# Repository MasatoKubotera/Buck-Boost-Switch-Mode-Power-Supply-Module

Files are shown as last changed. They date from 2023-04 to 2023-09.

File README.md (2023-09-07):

<html lang="en">

<head>
	<meta charset="uft-8">
	<meta name="author" content="Masato Kubotera">
    <meta name="description" content="">
</head>

<body>
    <p><strong>This product is currently under development!</strong></p>
	<h1>Buck-Boost Switch Mode Power Supply Module</h1>
        <p>
            <table>
                <tr>
                    <th>Top Surface of PCB</th>
                    <th>Bottom Surface of PCB</th>
                    <th>Assembled Electronic Components</th>
                </tr>
                <tr>
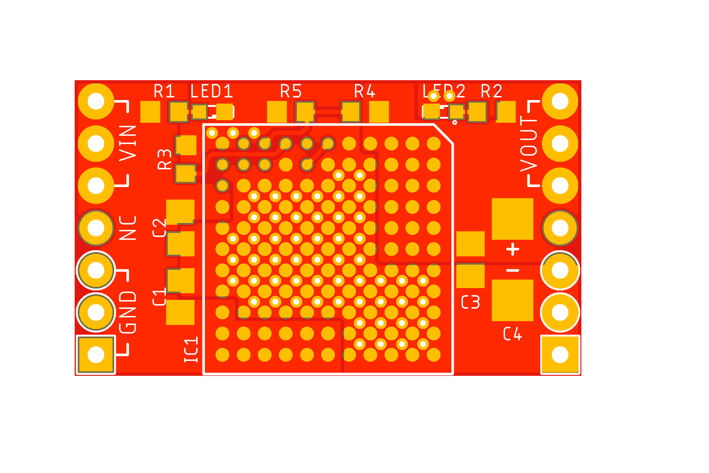
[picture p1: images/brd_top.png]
                    <td></td>
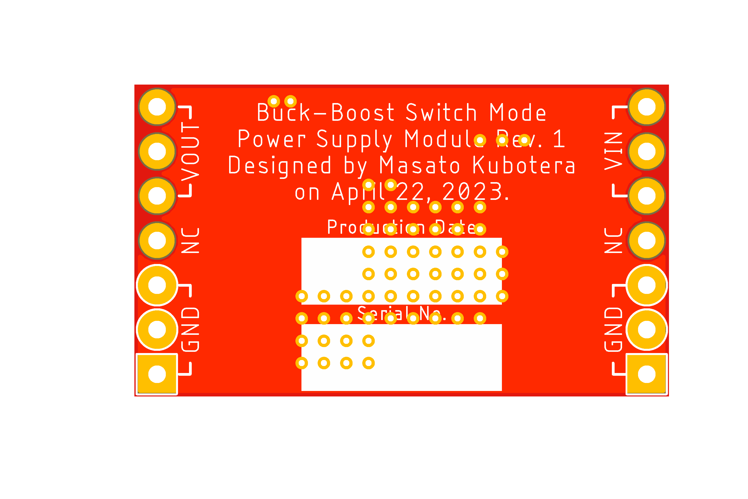
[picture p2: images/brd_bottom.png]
                    <td></td>
                    <td></td>
                </tr>
            </table>
        </p>
	<h2>Features Rev. 1</h2>
        <p>
            This product is a buck-boost switch mode power supply module using Analog Devices <a href="https://www.analog.com/en/products/ltm8055.html">LTM8055</a>. Supports the wide voltage input range of 5V to 36V. The output current and switching frequency are determined by the resistor value to be mounted.<br>
            This product was designed with a recommended 12V/6A output and a switching frequency of 600kHz. However, it was later changed to 18V/5A output and 800kHz switching frequency to suit SUSTAINA-OP<sup>TM</sup> applications.
        </p>
    <h3>PCB</h3>
        <p>
            <ul>
                <li>12" x 7" (30.48 mm x 17.78 mm) PCB layout</li>
                <li>1" (2.54mm) pitch through-holes for pin headers
                    <ul>
                        <li>1 x 7 pin headers - 1
                            <ul>
                                <li><strong>3x VIN</strong>: Power In (5V to 36V)</li>
                                <li><strong>1x NC</strong>: Non Connection</li>
                                <li><strong>3x GND</strong>: Common Ground</li>
                            </ul>
                        </li>
                        <li>1 x 7 pin headers - 2
                            <ul>
                                <li><strong>3x VOUT</strong>: Power Out (Regulated 18V)</li>
                                <li><strong>1x NC</strong> Non Connection</li>
                                <li><strong>3x GND</strong>: Common Ground</li>
                            </ul>
                        </li> 
                    </ul>
                </li>
            </ul>
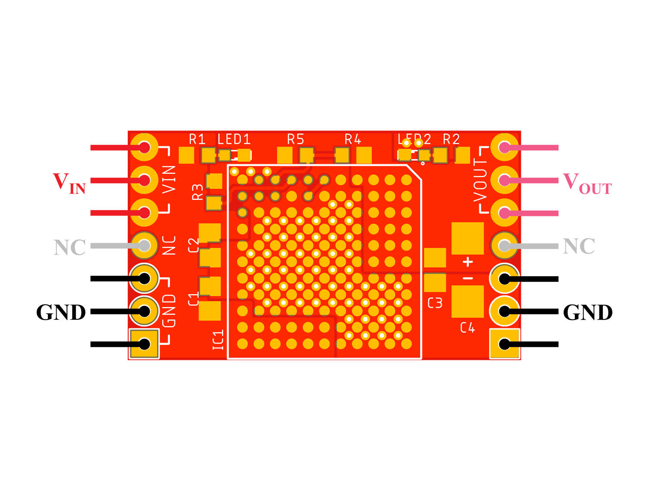
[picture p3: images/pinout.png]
            
        </p>
    <h3><a href="https://www.analog.com/en/products/ltm8055.html">LTM8055</a></h3>
        <p>
            <ul>
                <li>Complete Buck-Boost Switch Mode Power Supply</li>
                <li>VOUT Equal, Greater, Less Than VIN</li>
                <li>Wide Input Voltage Range: 5V to 36V</li>
                <li>12V/3A Output from 6VIN</li>
                <li>12V/6A Output from 12VIN</li>
                <li>12V/8.5A Output from 24VIN</li>
                <li>Up to 97.5% Efficient</li>
                <li>Adjustable Input and Output Average Current Limits</li>
            </ul>
        <p>
	<h2>Development Environments</h2>
    <p>
        This product is designed with the following software.
            <ul>
                <li><a href="https://www.autodesk.com/products/eagle/overview">Autodesk Eagle 9.6.2</a></li>
            </ul>
    </p>
    <h2>Repository Contents</h2>
        <p>
            <dl>
                <dt><a href="/images">\images</a></dt>
                <dd>PCB preview images and capture of design screen</dd>
                <dt><a href="/libraries">\libraries</a></dt>
                <dd>Libraries used in Autodesk Eagle design</dd>
                <dt><a href="/documents">\documents</a> </dt>
                <dd>Documentation for making and using this product</dd>
                <dt><a href="/pcb_order">\pcb_order</a> </dt>
                <dd>Gerber data and documentation for ordering PCB</dd>
                <dt><a href="/schematic.pdf">schematic.pdf</a></dt>
                <dd>Circuit diagram of this product</dd>
                <dt>*.brd</dt>
                <dd>Board wiring design file by Autodesk Eagle</dd>
                <dt>*.sch</dt>
                <dd>Circuit diagram design file by Autodesk Eagle</dd>
                <dt><a href="/.gitignore">.gitignore</a></dt>
                <dd>A file that tells Git not to track a particular file</dd>            <dt><a href="/LICENSE">LICENSE</a></dt>
                <dd>License to use this product</dd>
            </dl>
        </p>
    <h2>Documentation</h2>
        <p>
            The following documents are available for this product.
            <ul>
                <li><a href="/pcb_order/README.md">\pcb_order\README.md</a>: Information for ordering the PCB</li>
                <li><a href="/documents/BOM.md">\document\BOM.md</a>: List of electronic components assembled on the PCB</li>
            </ul>
        </p>
    <h3>Note</h3>
    <h4>Die due to temperature</h4>
        <p>
            The die temperature of the LTM8055/LTM8055-1 must be lower than the maximum rating of 125°C. Therefore, it is recommended that the following heat sinks be affixed to the LTM8055/LTM8055-1.<br>
            Details: <a href="https://www.analog.com/media/en/technical-documentation/data-sheets/LTM8055-8055-1.pdf#page=18">Analog Devices LTM8055/LTM8055-1 Data Sheet Page#18</a>
            <ul>
                <li><a href="https://amzn.asia/d/5Kmnowi">Awxlumv Aluminum Heatsink 14mm x 14mm x 6mm</a></li>
            </ul>
        </p>
    <h4>Output voltage and switching frequency</h4>
        <p>
            The output voltage of LTM8055/LTM8055-1 is determined by R4 and R5 on the board, and the switching frequency by R3. If the voltage is set other than the recommended configuration voltage, the voltage is determined by the following equation.<br>
            Output voltage [V] = 1.2 * (1 + R4 / R5)<br>
            Details: <a href="https://www.analog.com/media/en/technical-documentation/data-sheets/LTM8055-8055-1.pdf#page=10">Analog Devices LTM8055/LTM8055-1 Data Sheet Page#10</a>
        </p>
    <h2>References</h2>
        <p>
            This product was designed with reference to the following products.
            <ul>
                <li><a href="https://www.analog.com/jp/design-center/evaluation-hardware-and-software/evaluation-boards-kits/dc2017a.html">Analog Devices DC2017A: LTM8055 Demo Board</a></li>
            </ul>
        </p>
    <h2>Contact</h2>
        <p>
            If you have any questions, please contact the designer of this product, Masato Kubodera, by <a href="mailto:masato.kubotera@sustaina-op.com">e-mail</a>.<br>
            E-mail: <a href="mailto:masato.kubotera@sustaina-op.com">masato.kubotera@sustaina-op.com</a>
        </p>
    <h2>License Information</h2>
        <p>
            This product is open source. Please review the <a href="/LICENSE">LICENSE</a> for license information.<br>
            <br>
            This product by Masato Kubotera is licensed under a <a href="http://creativecommons.org/licenses/by-nc-sa/4.0/">Creative Commons Attribution-NonCommercial-ShareAlike 4.0 International License</a>.
        </p>
</body>
</html>

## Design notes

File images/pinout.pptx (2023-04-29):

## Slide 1

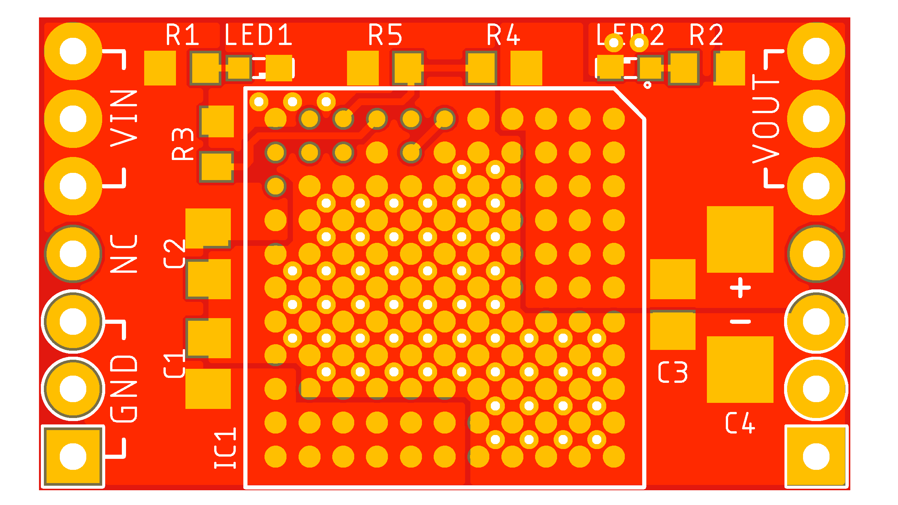
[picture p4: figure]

VOUT

NC

GND

VIN

NC

GND

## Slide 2

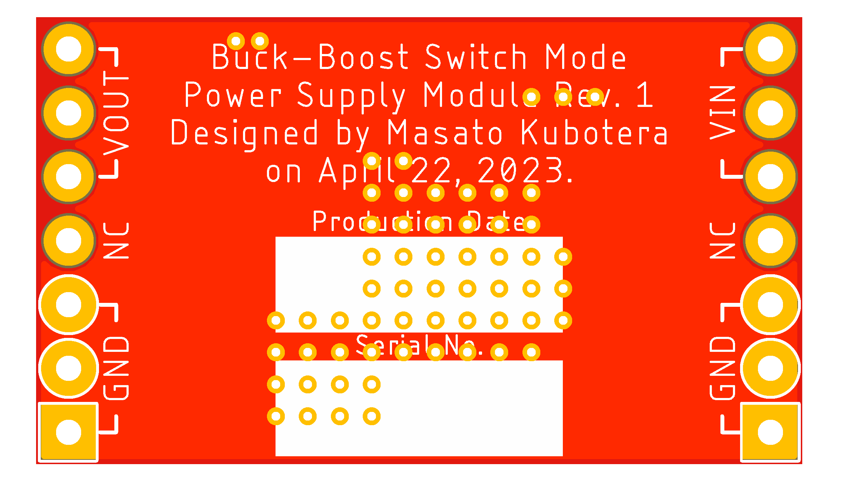
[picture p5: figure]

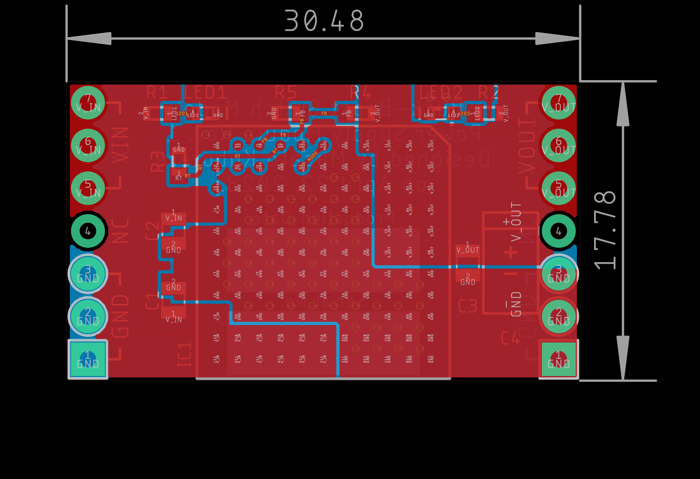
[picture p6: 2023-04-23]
images/brd.png

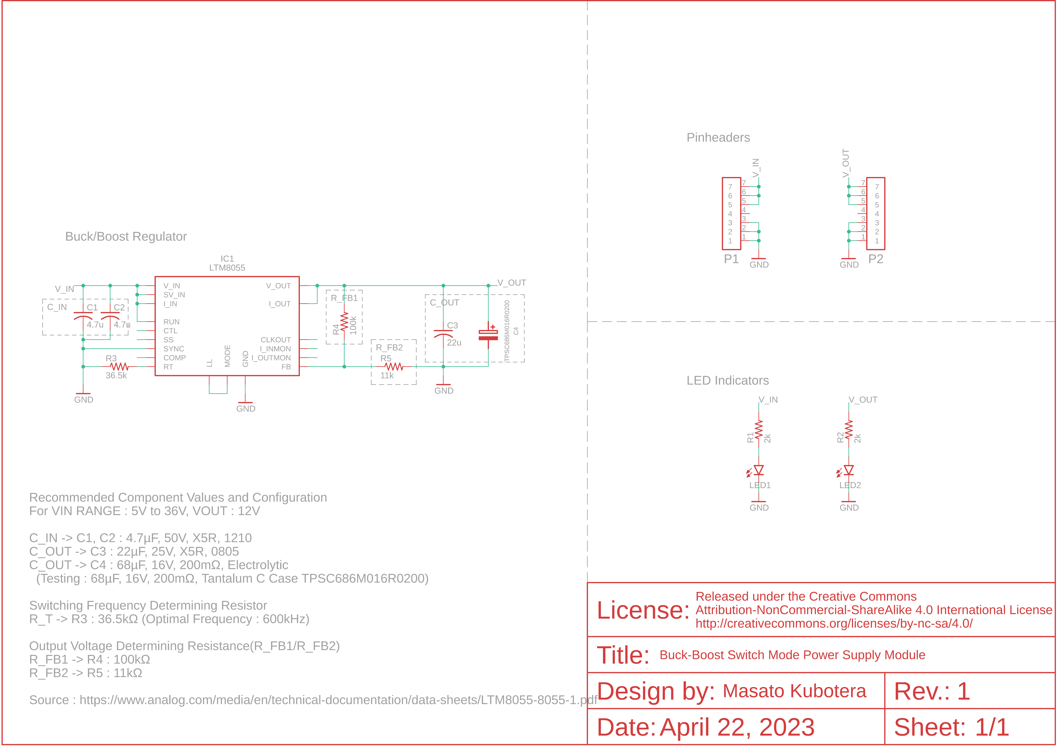
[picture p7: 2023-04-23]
images/sch.png

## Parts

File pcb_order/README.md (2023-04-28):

<html lang="en">

<head>
	<meta charset="uft-8">
	<meta name="author" content="Masato Kubotera">
    <meta name="description" content="">
</head>

<body>
	<h1>PCB Order</h1>
        <p>
            PCB ordering were outsourced to <a href="https://jlcpcb.com/">JLCPCB</a>.<br>
            The following files were used to generate files for PCB orders.
            <ul>
                <li>Eagle Design File:
                    <a href="https://github.com/JLCPCB/jlcpcb-eagle/blob/master/design%20rules/jlcpcb-2layers.dru">jlcpcb-2layers.dru</a>
                </li>
                <li>Eagle CAM File:
                    <a href="https://github.com/JLCPCB/jlcpcb-eagle/blob/master/cam/jlcpcb_2_layer_v9.cam">jlcpcb_2_layer_v9.cam</a>
                </li>
            </ul>
            These are distributed in <a href="https://github.com/JLCPCB/jlcpcb-eagle">github.com/JLCPCB/jlcpcb-eagle</a>.<br>
        </p>
    <h2>PCB Order Specifications</h2>
        <p>           
            <table>
                <tr>
                    <th>PCB Top Image</th>
                    <th>PCB Bottom Image</th>
                </tr>
                <tr>
                    <td></td>
                    <td></td>
                </tr>
            </table>
            The following files used to order the PCB and their specifications. 
            <ul>
                <li>Gerber data: <a href="Gerber_date.zip">Gerber_date.zip</a></li>
            </ul>
            <details close>
                <summary>Click for more specifications</summary>
                <ul>                
                    <li>Base Material: FR-4</li>
                    <li>Layers: 2</li>
                    <li>Dimension: 30.48mm* 17.78mm</li>
                    <li>Product Type: Industrial/Consumer electronics</li>
                    <li>Different Design: 1</li>
                    <li>Delivery Format: Single PCB</li>
                    <li>PCB Thickness: 1.6</li>
                    <li>Impedance Control: no</li>
                    <li>PCB Color: Red</li>
                    <li>Silkscreen: White</li>
                    <li>Surface Finish: HASL(with lead)</li>
                    <li>Outer Copper Weight: 1 oz</li>
                    <li>Via Covering: Tented</li>
                    <li>Board Outline Tolerance: ±0.2mm(Regular)</li>
                    <li>Confirm Production file: No</li>                
                    <li>Remove Order Number: Yes</li>
                    <li>Deburring/Edge rounding: No</li>
                    <li>Flying Probe Test: Fully Test</li>
                    <li>Gold Fingers: No</li>
                    <li>Castellated Holes: No</li>
                    <li>4-Wire Kelvin Test: No</li>
                    <li>Paper between PCBs: No</li>
                    <li>Appearance Quality: IPC Class 2 Standard</li>
                    <li>Silkscreen Technology: Ink-jet/Screen Printing</li>
                    <li>Package Box: With JLCPCB logo</li>
                </ul>
            </details>
        </p>
        <h2>SMT Stencil Order Specifications</h2>
        <p>           
            <details close>
                <summary>Click for more specifications</summary>
                <ul>                
                    <li>Framework: No</li>                
                    <li>Step Stencil: No</li>                
                    <li>Dimension: 380mm*280mm</li>                
                    <li>Stencil Side: Top</li>                
                    <li>Electropolishing: Sanding</li>                
                    <li>Fiducials: No Fiducial</li>                
                    <li>Confirm Production file:: No</li>
                </ul>
            </details>
        </p>
</body>
</html>

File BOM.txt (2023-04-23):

Qty Value            Device           Package          Parts      Description                
2                    LEDSML0603       SML0603          LED1, LED2 LED                        
1   100k             R-US_R0603       R0603            R4         RESISTOR, American symbol  
1   11k              R-US_R0603       R0603            R5         RESISTOR, American symbol  
1   22u              C-USC0805        C0805            C3         CAPACITOR, American symbol 
2   2k               R-US_R0603       R0603            R1, R2     RESISTOR, American symbol  
1   36.5k            R-US_R0603       R0603            R3         RESISTOR, American symbol  
2   4.7u             C-USC0805        C0805            C1, C2     CAPACITOR, American symbol 
1   LTM8055          LTM8055          LTM8055          IC1                                   
2   PINHEADER-7P     PINHEADER-7P     7P               P1, P2                                
1   TPSC686M016R0200 TPSC686M016R0200 TPSC686M016R0200 C4

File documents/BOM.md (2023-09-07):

<html lang="en">

<head>
	<meta charset="uft-8">
	<meta name="author" content="Masato Kubotera">
    <meta name="description" content="">
</head>

<body>
	<h1>BOM</h1>
        <p>
        The following electronic components are used for assembly on the PCB.
        <table>
                <tr>
                    <th>Top Designator</th>
                    <th>MFR.Part #</th>
                    <th>Distributor / Part #</th>
                    <th>Manufacturer</th>
                    <th>Part Detail</th>
                </tr>
                <tr>
                    <td>IC1</td>
                    <td>LTM8055IY#PBF</td>
                    <td><a href="https://www.mouser.jp/ProductDetail/584-LTM8055IY%23PBF">Mouser / 584-LTM8055IY#PBF</a></td>
                    <td><a href="https://www.analog.com/en/products/ltm8055.html">Analog Devices</a></td>
                    <td>Switching Voltage Regulator SMD Buck-Boost 36V 8.5A BGA-121</td>
                </tr>
                <tr>
                    <td>C1, C2</td>
                    <td>CL21A475KBQNNNE</td>
                    <td><a href="https://akizukidenshi.com/catalog/g/gP-07548/">Akizuki / P-07548</a></td>
                    <td><a href="https://product.samsungsem.com/mlcc/CL21A475KBQNNN.do">Samsung Electronics</a></td>
                    <td>Multilayer Ceramic Capacitor SMD 4.7uF 50V ±10% X5R 0805</td>
                </tr>
                <tr>
                    <td>C3</td>
                    <td>GRM21BR61E226ME44</td>
                    <td><a href="https://akizukidenshi.com/catalog/g/gP-08240/">Akizuki / P-08240</a></td>
                    <td><a href="https://www.murata.com/en-us/products/productdetail?partno=GRM21BR61E226ME44%23">Murata Electronics</a></td>
                    <td>Multilayer Ceramic Capacitor SMD 22uF 25V ±20% X5R 0805</td>
                </tr>
                <tr>
                    <td>C4</td>
                    <td>TPSC686M016R0200</td>
                    <td><a href="https://www.mouser.jp/ProductDetail/581-TPSC686M016R0200">Mouser / 581-TPSC686M016R0200</a></td>
                    <td><a href="https://www.kyocera-avx.com/products/tantalum/smd-tantalum-mno2/tps-series/">KYOCERA AVX</a></td>
                    <td>Tantalum Capacitor SMD 68uF 16V ±20% 2312</td>
                </tr>
                <tr>
                    <td>LED1, LED2</td>
                    <td>150060VS86000</td>
                    <td><a href="https://www.mouser.jp/ProductDetail/710-150060VS86000">Mouser / 710-150060VS86000</a></td>
                    <td><a href="https://www.we-online.com/components/products/datasheet/150060VS86000.pdf">Wurth Elektronik</a></td>
                    <td>Standard LED SMD 2V 20mA GREEN 573nm 0603</td>
                </tr>
                <tr>
                    <td>P1, P2</td>
                    <td>PH-1x40SG</td>
                    <td><a href="https://akizukidenshi.com/catalog/g/gC-00167/">Akizuki / C-00167</a></td>
                    <td><a href="">Useconn Electronics</a></td>
                    <td>Pin Header Straight 2.54mm Pitch 3A 20mΩ 500V</td>
                </tr>
                <tr>
                    <td>R1, R2</td>
                    <td>RC0603FR-102KL</td>
                    <td><a href="https://www.mouser.jp/ProductDetail/603-RC0603FR-102KL">Mouser / 603-RC0603FR-102KL</a></td>
                    <td>YAGEO</td>
                    <td>Thick Film Resistor SMD 2kΩ 1/10W ±1% 0603</td>
                </tr>
                <tr>
                    <td>R3</td>
                    <td>CPF0603B45K3E1</td>
                    <td><a href="https://jp.rs-online.com/web/p/surface-mount-resistors/1228879">RS Components /122-8879 </a></td>
                    <td>TE Connectivity</td>
                    <td>Thick Film Resistor SMD 45.3kΩ 0.063W ±0.1% 0603</td>
                </tr>
                <tr>
                    <td>R4</td>
                    <td>RC0603FR-07100KL</td>
                    <td><a href="https://www.mouser.jp/ProductDetail/603-RC0603FR-07100KL">Mouser / 603-RC0603FR-07100KL</a></td>
                    <td>YAGEO</td>
                    <td>Thick Film Resistor SMD 100kΩ 1/10W ±1% 0603</td>
                </tr>
                <tr>
                    <td>R5</td>
                    <td>ERA3APB6981V</td>
                    <td><a href="https://jp.rs-online.com/web/p/surface-mount-resistors/8409357">RS Components / 840-9357L</a></td>
                    <td>Panasonic</td>
                    <td>Thick Film Resistor SMD 6.98kΩ 1/10W ±0.1% 0603</td>
                </tr>
            </table>
            For a configuration with output voltage/current of 12V/6A, change to the following.
            <table>
                <tr>
                    <th>Top Designator</th>
                    <th>MFR.Part #</th>
                    <th>Distributor / Part #</th>
                    <th>Manufacturer</th>
                    <th>Part Detail</th>
                </tr>
                <tr>
                    <td>R3</td>
                    <td>RC0603FR-0736K5L</td>
                    <td><a href="https://www.mouser.jp/ProductDetail/603-RC0603FR-0736K5L">Mouser /603-RC0603FR-0736K5L </a></td>
                    <td>YAGEO</td>
                    <td>Thick Film Resistor SMD 36.5kΩ 1/10W ±1% 0603</td>
                </tr>
                <tr>
                    <td>R5</td>
                    <td>RC0603JR-0711KL</td>
                    <td><a href="https://www.mouser.jp/ProductDetail/603-RC0603JR-0711KL">Mouser / 603-RC0603JR-0711KL</a></td>
                    <td>YAGEO</td>
                    <td>Thick Film Resistor SMD 11kΩ 1/10W ±1% 0603</td>
                </tr>
            </table>
        </p>
</body>
</html>

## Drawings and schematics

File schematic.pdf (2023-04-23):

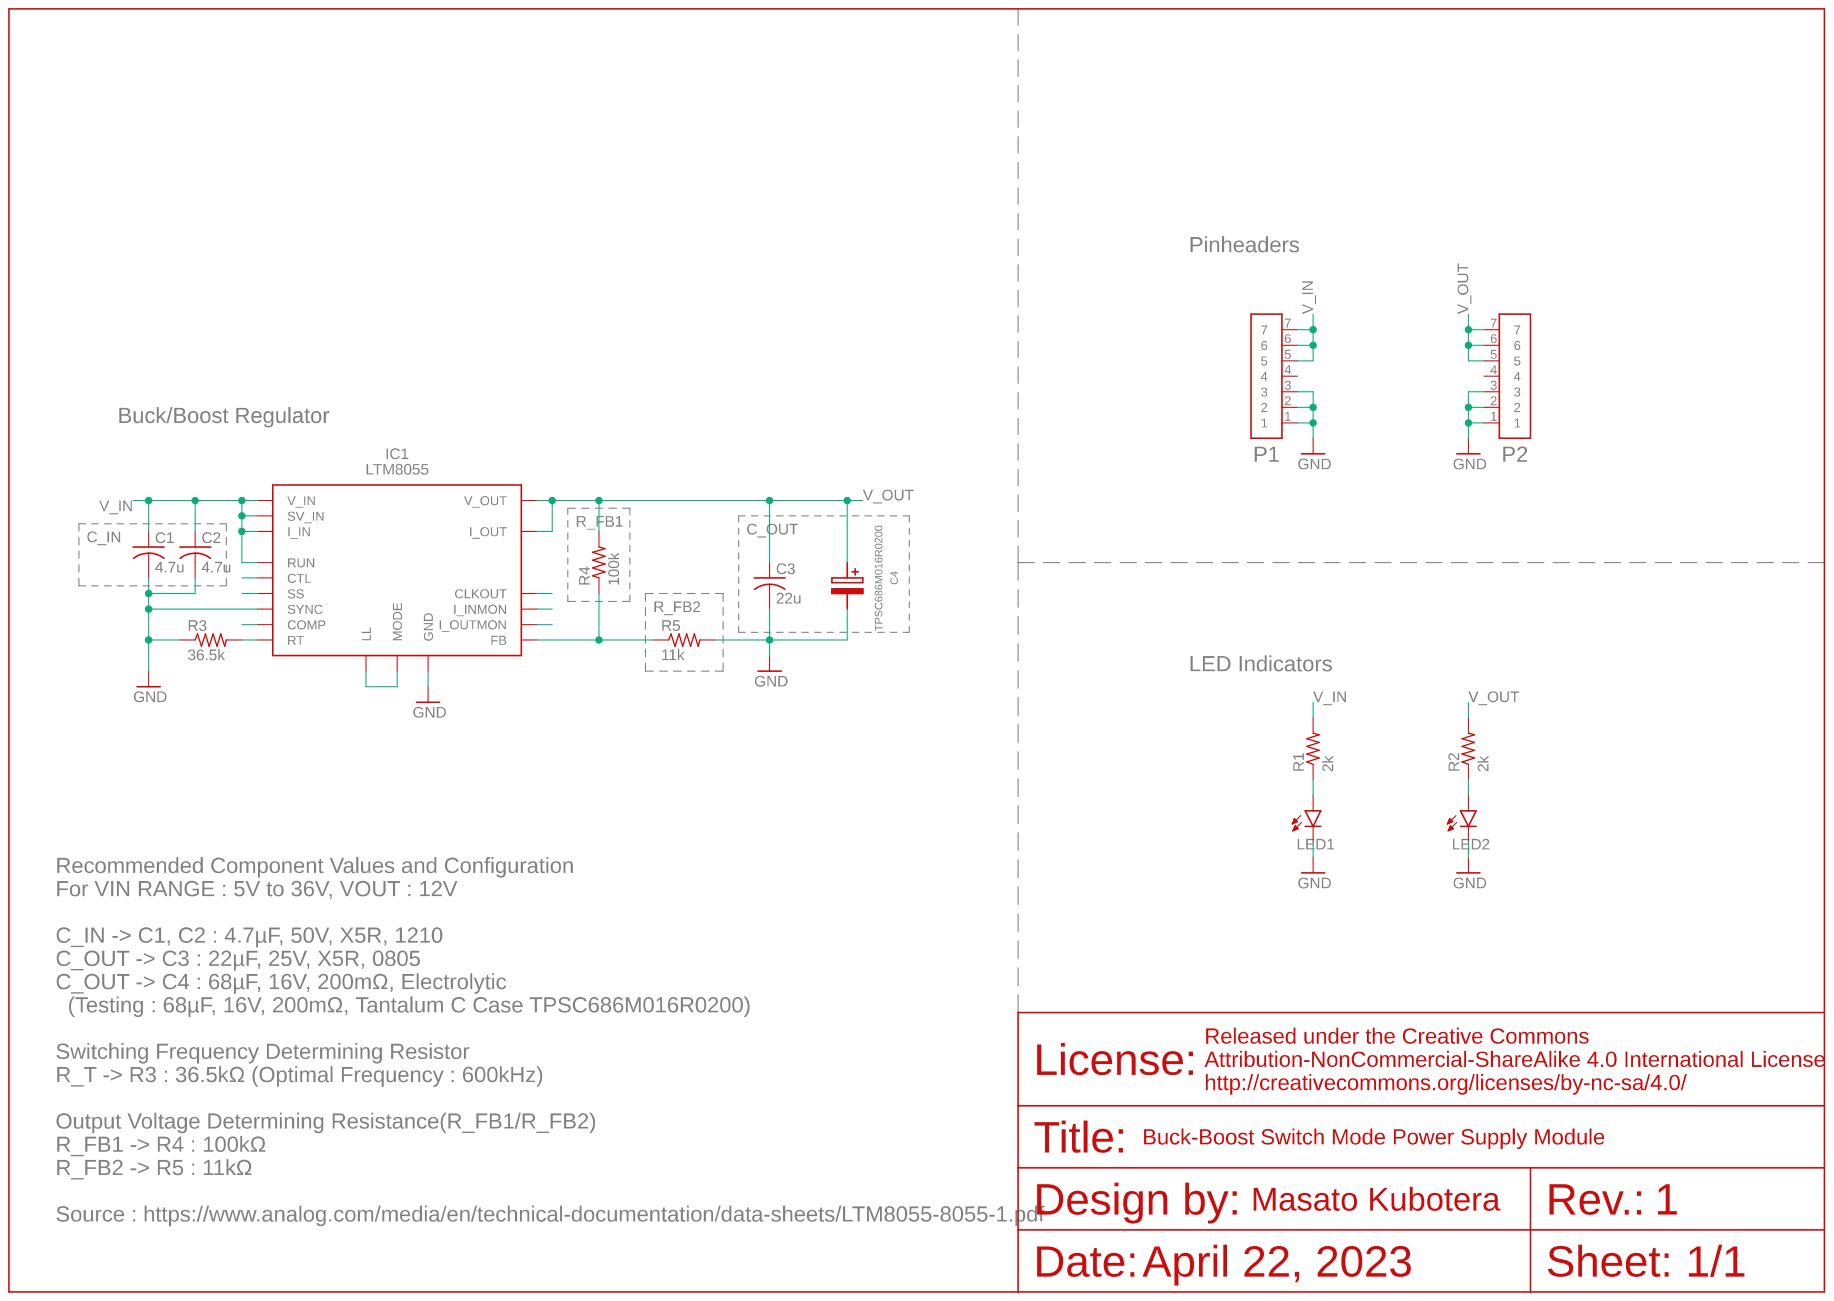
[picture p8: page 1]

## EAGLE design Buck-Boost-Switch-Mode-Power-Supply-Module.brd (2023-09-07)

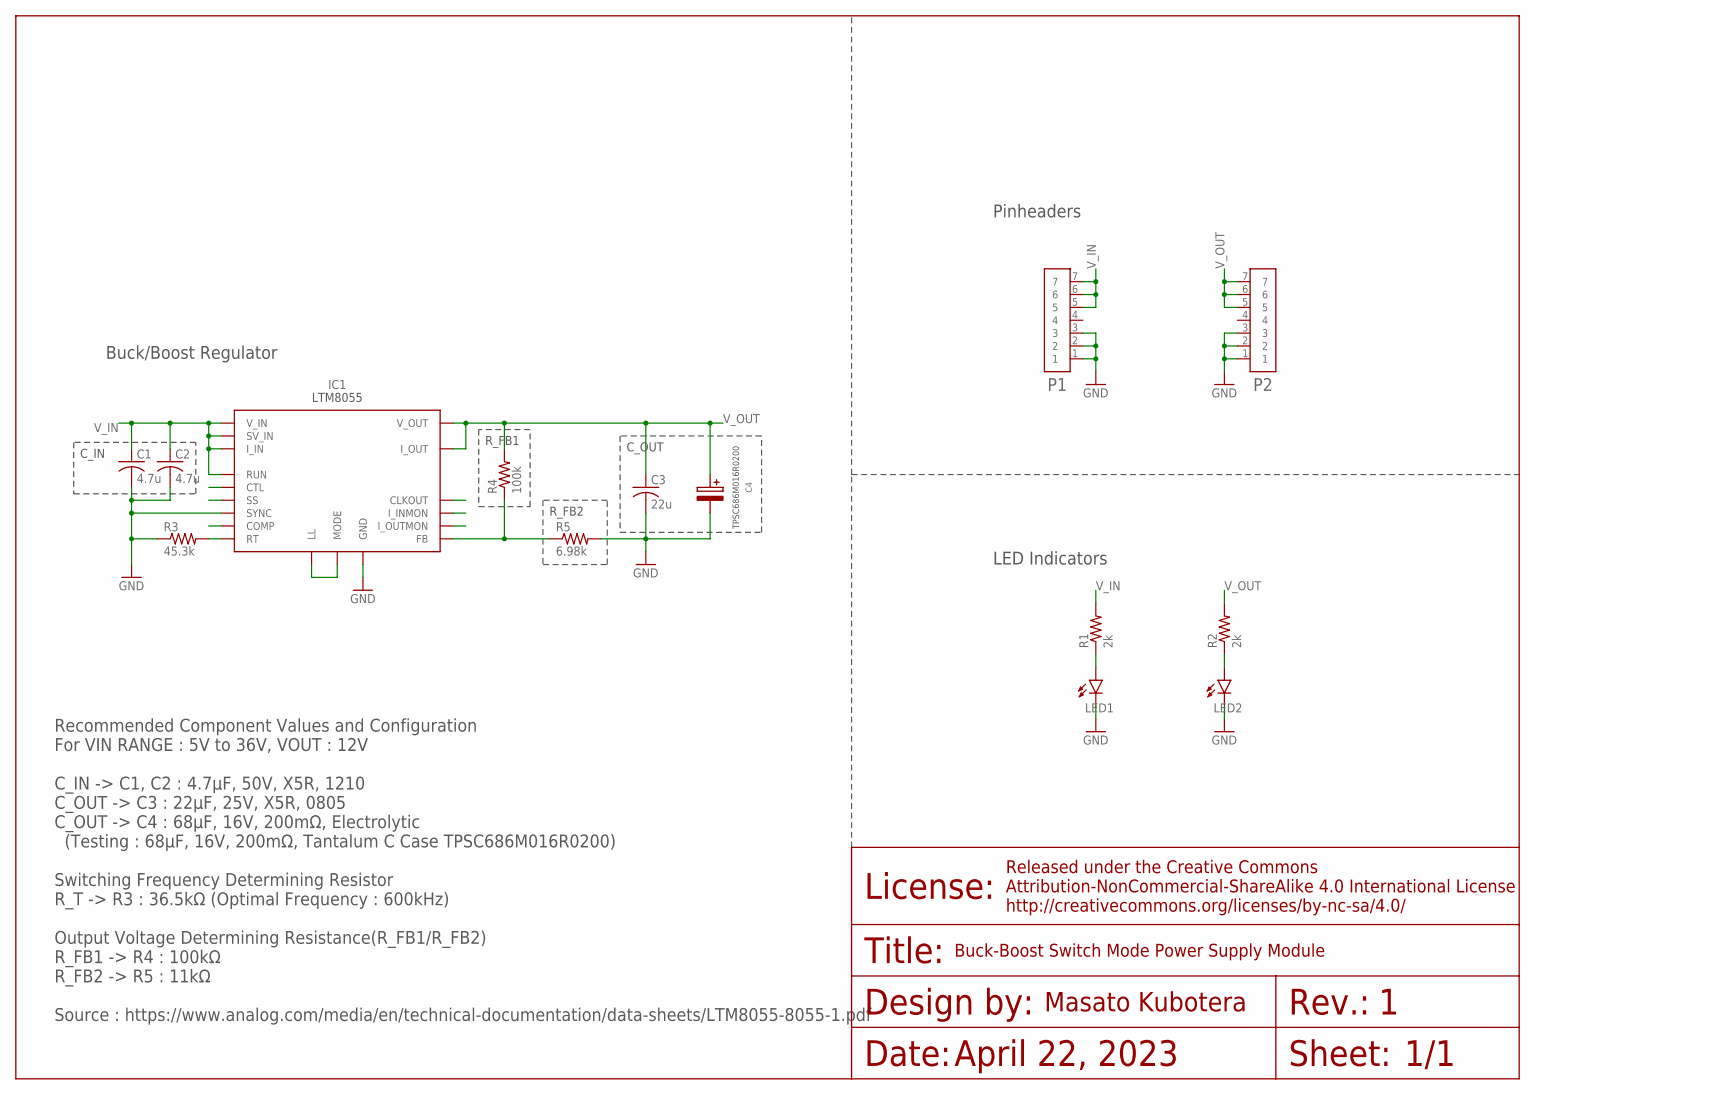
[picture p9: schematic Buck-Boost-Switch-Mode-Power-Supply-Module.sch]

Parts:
C1, C2: 4.7u; C0805
C3: 22u; C0805
C4: TPSC686M016R0200
IC1: LTM8055
LED1, LED2: LEDSML0603; SML0603
P1, P2: PINHEADER-7P; 7P
R1, R2: 2k; R0603
R3: 45.3k; R0603
R4: 100k; R0603
R5: 6.98k; R0603

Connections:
CLKOUT: IC1.G1 (CLKOUT)
COMP: IC1.J2 (COMP)
FB: IC1.J1 (FB), R4.1, R5.1
GND: C1.2, C2.2, C3.2, C4.-, IC1.A7 (GND), IC1.A8 (GND), IC1.A9 (GND), IC1.A10 (GND), IC1.A11 (GND), IC1.B7 (GND), IC1.B8 (GND), IC1.B9 (GND), IC1.B10 (GND), IC1.B11 (GND), IC1.C7 (GND), IC1.C8 (GND), IC1.C9 (GND), IC1.C10 (GND), IC1.C11 (GND), IC1.D2 (GND), IC1.D3 (GND), IC1.D4 (GND), IC1.D5 (GND), IC1.D6 (GND), IC1.D7 (GND), IC1.D8 (GND), IC1.D9 (GND), IC1.D10 (GND), IC1.D11 (GND), IC1.E1 (GND), IC1.E2 (GND), IC1.E3 (GND), IC1.E4 (GND), IC1.E5 (GND), IC1.E6 (GND), IC1.E7 (GND), IC1.E8 (GND), IC1.E9 (GND), IC1.E10 (GND), IC1.E11 (GND), IC1.F2 (GND), IC1.F3 (GND), IC1.F4 (GND), IC1.F5 (GND), IC1.F6 (GND), IC1.F7 (GND), IC1.F8 (GND), IC1.F9 (GND), IC1.G3 (GND), IC1.G4 (GND), IC1.G5 (GND), IC1.G6 (GND), IC1.G7 (GND), IC1.G8 (GND), IC1.G9 (GND), IC1.H2 (SYNC), IC1.H3 (GND), IC1.H4 (GND), IC1.H5 (GND), IC1.H6 (GND), IC1.H7 (GND), IC1.H8 (GND), IC1.H9 (GND), IC1.J3 (GND), IC1.J4 (GND), IC1.J5 (GND), IC1.J6 (GND), IC1.J7 (GND), IC1.J8 (GND), IC1.J9 (GND), IC1.K3 (GND), IC1.K4 (GND), IC1.K5 (GND), IC1.K6 (GND), IC1.K7 (GND), IC1.K8 (GND), IC1.K9 (GND), IC1.L1 (GND), IC1.L5 (GND), IC1.L6 (GND), IC1.L7 (GND), IC1.L8 (GND), LED1.C, LED2.C, P1.1, P1.2, P1.3, P2.1, P2.2, P2.3, R3.1, R5.2
I_INMON: IC1.L3 (I_INMON)
I_OUTMON: IC1.L2 (I_OUTMON)
LED1: LED1.A, R1.1
LED2: LED2.A, R2.1
MODE: IC1.F1 (LL), IC1.G2 (MODE)
RT: IC1.H1 (RT), R3.2
SS: IC1.K1 (SS)
STL: IC1.K2 (CTL)
V_IN: C1.1, C2.1, IC1.F10 (SV_IN), IC1.F11 (SV_IN), IC1.G10 (V_IN), IC1.G11 (V_IN), IC1.H10 (V_IN), IC1.H11 (V_IN), IC1.J10 (V_IN), IC1.J11 (V_IN), IC1.K10 (V_IN), IC1.K11 (V_IN), IC1.L4 (RUN), IC1.L9 (I_IN), IC1.L10 (V_IN), IC1.L11 (V_IN), P1.5, P1.6, P1.7, R1.2
V_OUT: C3.1, C4.+, IC1.A1 (V_OUT), IC1.A2 (V_OUT), IC1.A3 (V_OUT), IC1.A4 (V_OUT), IC1.A5 (V_OUT), IC1.A6 (V_OUT), IC1.B1 (V_OUT), IC1.B2 (V_OUT), IC1.B3 (V_OUT), IC1.B4 (V_OUT), IC1.B5 (V_OUT), IC1.B6 (V_OUT), IC1.C1 (V_OUT), IC1.C2 (V_OUT), IC1.C3 (V_OUT), IC1.C4 (V_OUT), IC1.C5 (V_OUT), IC1.C6 (V_OUT), IC1.D1 (I_OUT), P2.5, P2.6, P2.7, R2.2, R4.2

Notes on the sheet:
1/1
April 22, 2023
Buck-Boost Switch Mode Power Supply Module
Buck/Boost Regulator
LED Indicators
Pinheaders
Recommended Component Values and Configuration For VIN RANGE : 5V to 36V, VOUT : 12V C_IN -> C1, C2 : 4.7µF, 50V, X5R, 1210 C_OUT -> C3 : 22µF, 25V, X5R, 0805 C_OUT -> C4 : 68µF, 16V, 200mΩ, Electrolytic (Testing : 68µF, 16V, 200mΩ, Tantalum C Case TPSC686M016R0200) Switching Frequency Determining 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
C_IN
C_OUT
R_FB1
R_FB2

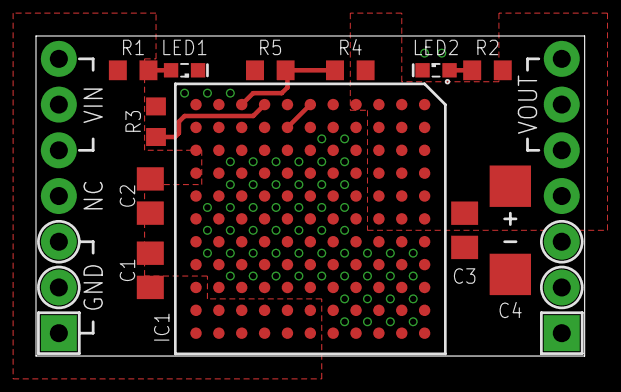
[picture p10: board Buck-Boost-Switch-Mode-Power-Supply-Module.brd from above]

Board: 2 copper layers, 30.5 x 17.8 mm, 14 parts (0 on the bottom side), 8 nets.

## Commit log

2023-04-23 Initial Upload
    [Buck-Boost-Switch-Mode-Power-Supply-Module.brd, Buck-Boost-Switch-Mode-Power-Supply-Module.sch]
2023-04-28 Created README.md of PCB ordering
2023-09-07 Changed to 18V output configuration used in RoboCup2023
    [Buck-Boost-Switch-Mode-Power-Supply-Module.brd, Buck-Boost-Switch-Mode-Power-Supply-Module.sch]

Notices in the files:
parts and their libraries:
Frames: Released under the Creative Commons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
